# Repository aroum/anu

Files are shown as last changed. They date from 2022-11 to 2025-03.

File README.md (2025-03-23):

# Anu

[Anu](https://en.wikipedia.org/wiki/Anu) - compact stick mouse.

Gerber files and stl models can be downloaded in [releases](https://github.com/aroum/anu/releases).

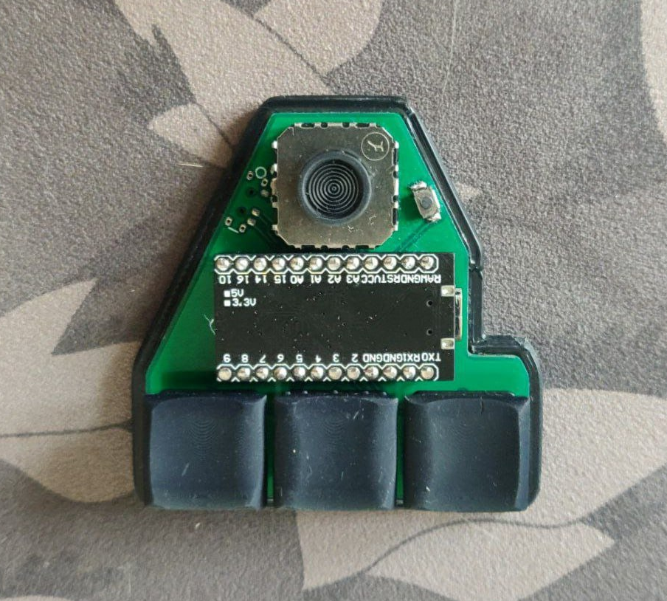
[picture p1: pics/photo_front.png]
front


# Features
* PSP analog stick 
* 3 keys, Kailh Choc V1 switches
* Choc spacing
* Direct pins 
* Wireless(optional)
* Per switch RGB(optional)
* Power switch for wireless controllers(optional)
* 100x100 mm panel pcb

# Firmware

Anu can be used with [nRFMicro](https://github.com/joric/nrfmicro) or [nice!nano](https://nicekeyboards.com/nice-nano/) and 301230 batteries for wireless mode. Currently ZMK does not support analog sticks.

The original idea was to create a compact "mouse" ([layout](http://www.keyboard-layout-editor.com/#/gists/458957846f6c65296a02e8bd9ae2c3ca)), but it can also be used as a gamepad. Gamepad firmare use [ArduinoGamepad library](https://github.com/gamelaster/ArduinoGamepad). For more detailed settings of the gamepad, you can use [TocaEdit XBOX 360 CE](https://www.x360ce.com/).

You can use the [threeboard layout](https://github.com/taylorconor/threeboard) to enter text using Anu.

Other configs using the analog stick [1](https://blog.ffff.lt/posts/joystick-algorithms/) & [2](https://github.com/CarrasTec/JoystickQMK/tree/main/macrokrs).

Work on ZMK support is also [in progress](https://github.com/aroum/zmk-anu/).

# BOM

| Item | Quantity | Remarks |
| --- | ---: | --- |
| [proMicro](https://aliexpress.ru/item/32840365436.html) | 1 | or any other compatible controller |
| [Kailh Choc V1](https://aliexpress.ru/item/32959996455.html) | 3  switches |
| [FJ08K-S](https://aliexpress.ru/item/1005006435837883.html) or [FJ08K](https://aliexpress.ru/item/32979957864.html) | 1 | analog stick. FJ08K-S has an additional button  |
| [Keycaps](https://aliexpress.ru/item/33026798318.html) | 3 | 1U |
| [YS-SK6812MINI-E](https://aliexpress.ru/item/4000475685852.html) | 3 | RGB leds |
| [Magnets](https://aliexpress.ru/item/1005002757445161.html) | 3-5 | disc 7x2 mm (for case) |
| [Bumpon](https://aliexpress.ru/item/4001188580018.html) | 8 | 5x2 mm |
| [Sockets PH3.5](https://aliexpress.ru/item/32899635835.html) | 12x2 | for controller |
| [SMD button 3x4x2mm](https://aliexpress.ru/item/1005003812819985.html) | 1 | for reset |
| [MSK-12C02](https://aliexpress.ru/item/1005001398386692.html) | 1 | Power switch  (wireless only) |
| [301230](https://aliexpress.ru/item/32732458079.html) | 1 | Battery  (wireless only) |
| [m2 nuts](https://aliexpress.ru/item/1005003114659036.html) | 4 | for case |
| [m2x4 screws](https://aliexpress.ru/item/1005004494509456.html) | 4 | for case |

[IBOM](https://htmlpreview.github.io/?https://github.com/aroum/anu/blob/master/pcb/ibom/ibom.html)

# Build guide
1. Solder the controller sockets
2. Solder the power switch (wireless only)
3. Solder the reset button
4. Solder the battery (only for wireless version)
5. Solder analog stick
6. Solder the pins into the controller
7. Solder 3 Kailh Choc V1 switches 
8. Solder 3 LEDs (RGB version only)
9. Put the keycaps on the switches and analog stick
10. Stick bumpon or place the keyboard in the case
11. Insert controller into sockets
12. Flash the bootloader (see the official manual for the controller)
13. Flash the firmware (see the official manual for the controller)

[Soldering Tutorial for Beginners](https://mightyohm.com/files/soldercomic/FullSolderComic_EN.pdf) ([RU version](https://sho0.neocities.org/downloads/komiks_payat_prosto.pdf))

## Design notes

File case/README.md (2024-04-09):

# CASE
 
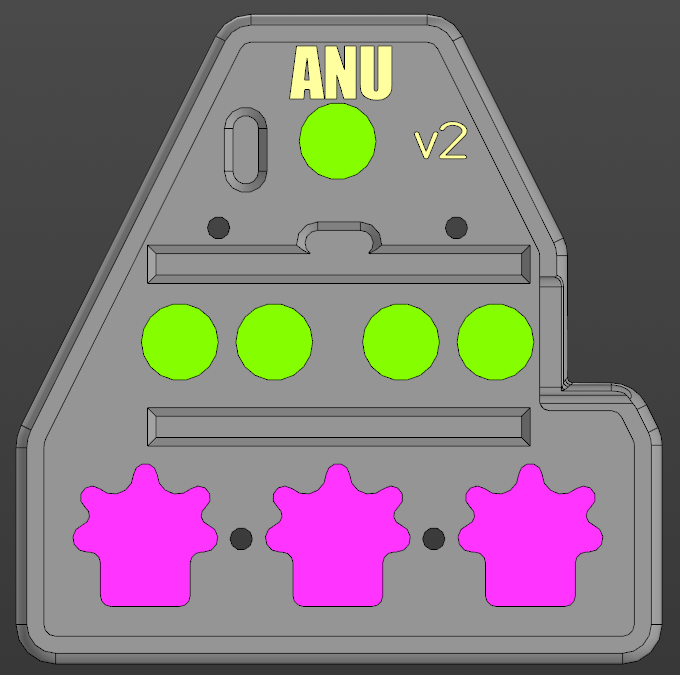
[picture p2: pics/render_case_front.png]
front

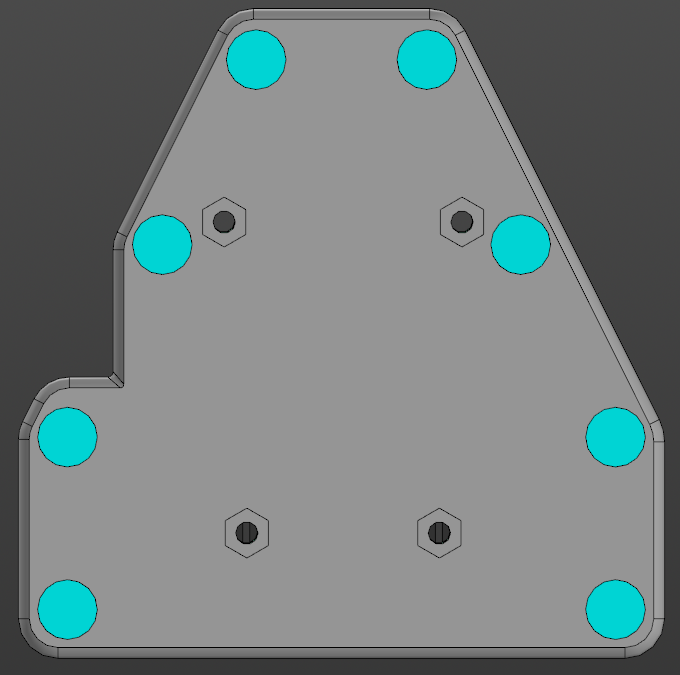
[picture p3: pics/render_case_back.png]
back


The pcb is fixed by friction or double-sided tape.

# BOM
* magnets size: 7x2mm (3-5 pcs)
* bumpons size: 5x2mm (8 pcs)
* nuts size: m2 (4 pcs)
* screws size: m2x4 (4 pcs)

# Print options:
* Printer: Voxelab proxima
* Rafts: No
* Supports: Yes
* Resolution: 0.05mm
* Resin material: ABS-like

The flexible version of the body does not have holes for non-slip feet.

STL and STEP models can be downloaded in [releases](https://github.com/aroum/anu/releases).

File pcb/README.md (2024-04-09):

# PCB
 
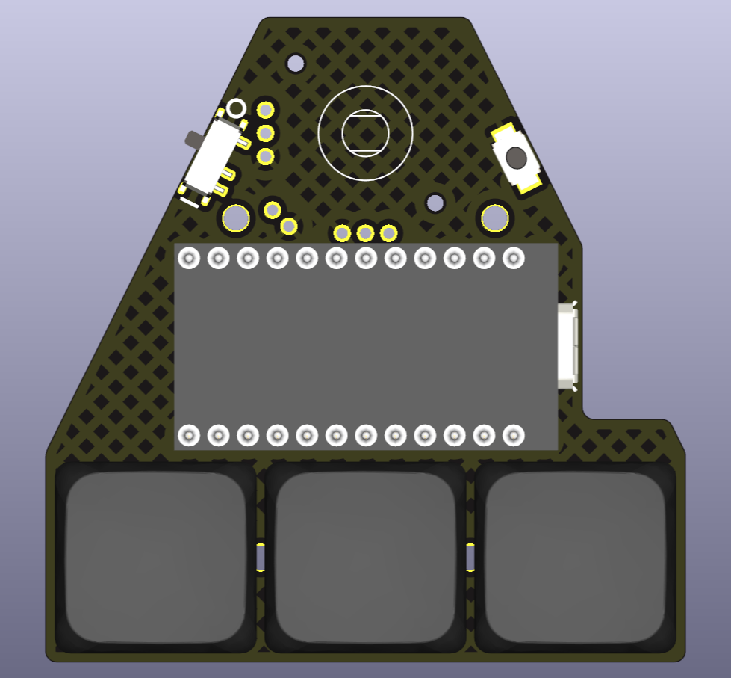
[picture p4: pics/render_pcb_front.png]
front

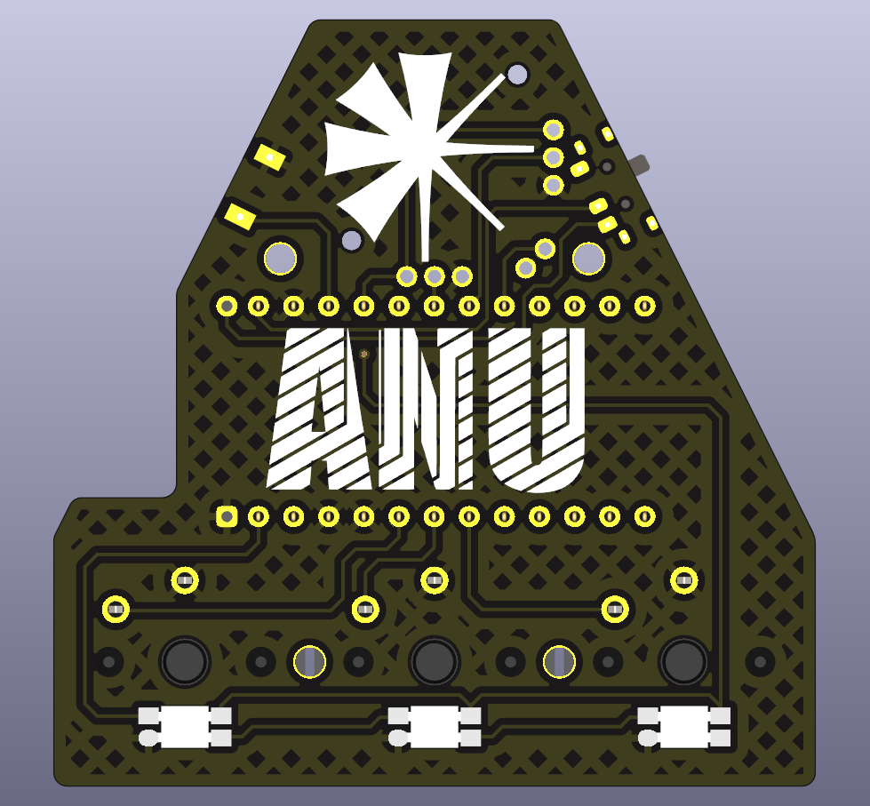
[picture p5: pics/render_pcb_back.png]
back


There is also the option of two PCBs fitted into 100x100 mm.

Gerber files can be downloaded in [releases](https://github.com/aroum/anu/releases).

[IBOM](https://htmlpreview.github.io/?https://github.com/aroum/anu/blob/master/pcb/ibom/ibom.html)

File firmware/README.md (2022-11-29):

# Firmware

## KLE

[Layout on the KLE website](http://www.keyboard-layout-editor.com/#/gists/458957846f6c65296a02e8bd9ae2c3ca)

## QMK
 
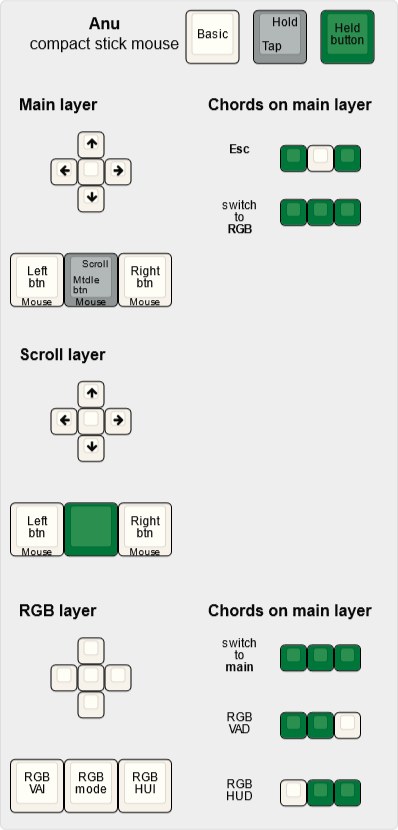
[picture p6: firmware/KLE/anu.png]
layout


* copy folder QMK/anu to qmk/keyboards
* run ```qmk compile -kb anu -km default```

Or just download in [releases](https://github.com/aroum/anu/releases).

## ZMK

Waiting for adding support mouse and analog read func.

## Arduino
* install [arduino gamepad lib](https://github.com/elanthis/gamepad)
* build
* install [x360ce](https://www.x360ce.com/) [optional]

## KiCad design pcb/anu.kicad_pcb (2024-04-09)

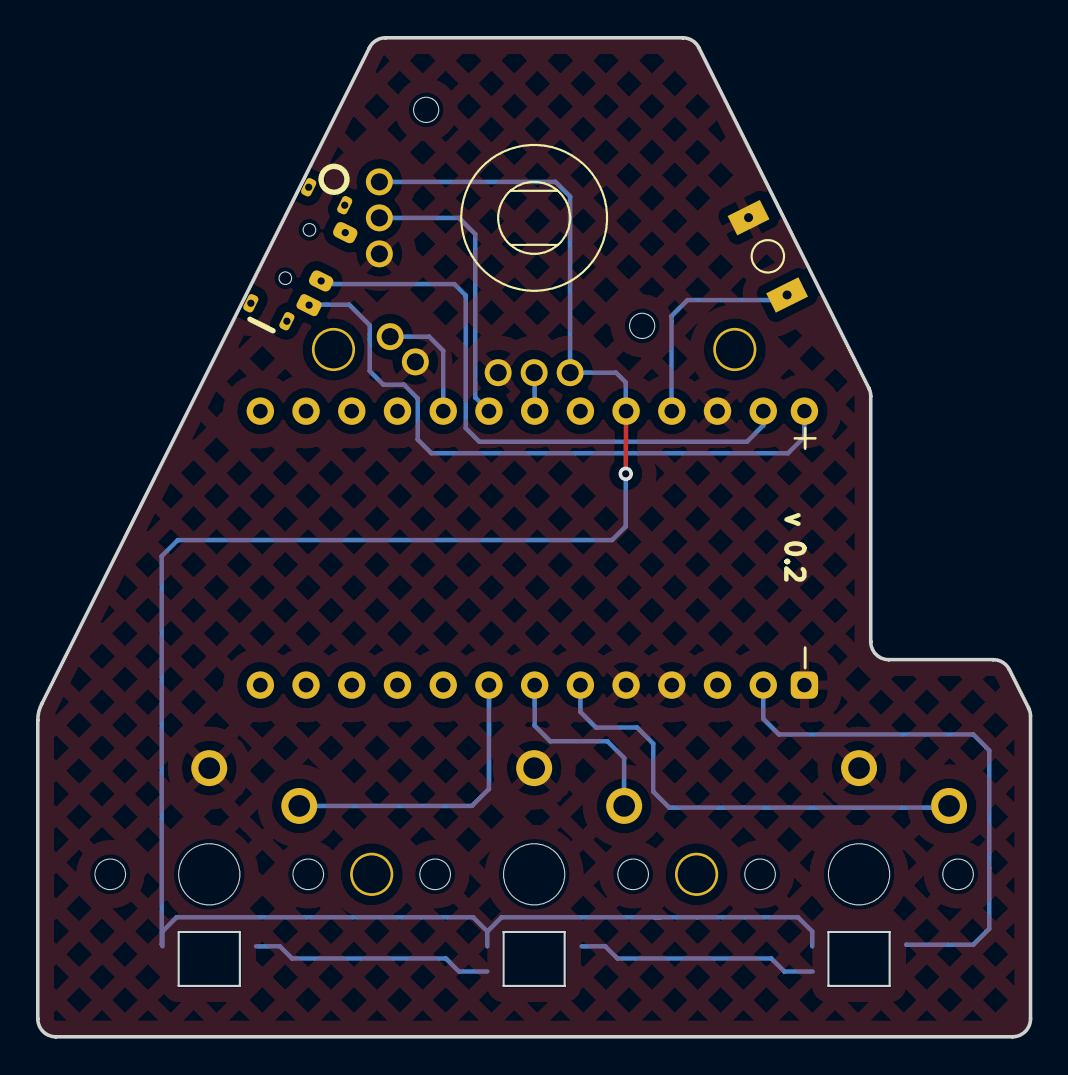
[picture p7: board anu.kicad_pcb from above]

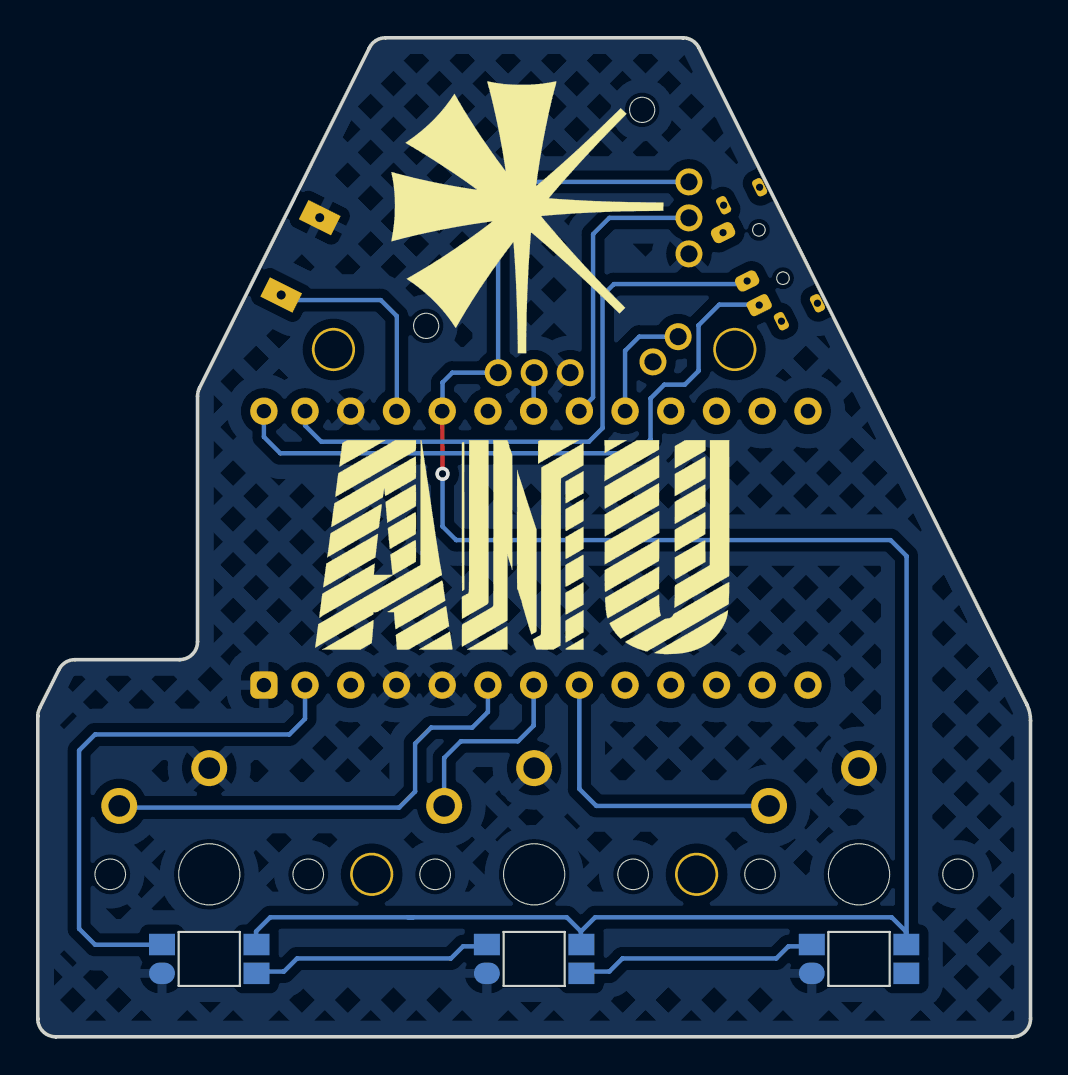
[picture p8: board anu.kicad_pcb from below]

Board: 2 copper layers, 55.2 x 55.5 mm, 17 parts (5 on the bottom side), 14 nets.

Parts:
G1: Logo; Logo_anu_cuneiform
G2: Logo; Logo_anu
H1, H1#2, H1#3, H1#4: Hole; HOLE
J1: battery connector; battery_conn_duplex
LED1, LED2, LED3: YS-SK6812MINI-E; YS-SK6812MINI-E_small
RSW1: SW_PUSH; SW_3x4x2_2legs
SW1, SW2, SW3: SW_PUSH; ChocV1_1u
SW4: SW_SPDT; SW_MSK-12C02_duplex
U1: ProMicro_r; ProMicro_v4
X1: FJ08K-S

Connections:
GND: J1.2, LED1.3 (GND), LED2.3 (GND), LED3.3 (GND), RSW1.2, SW1.2, SW2.2, SW3.2, U1.3 (GND), U1.4 (GND), U1.23 (GND), X1.A (SW1), X1.X3 (VCC), X1.Y1 (VCC)
LED: LED3.4 (DIN), U1.1 (D3/TX0)
unnamed: J1.1, SW4.3 (C)
unnamed: LED1.4 (DIN), LED2.2 (DOUT)
unnamed: LED2.4 (DIN), LED3.2 (DOUT)
VBAT: SW4.2 (B), U1.24 (RAW)
VCC: LED1.1 (VDD), LED2.1 (VDD), LED3.1 (VDD), U1.21 (VCC), X1.X1 (GND), X1.Y3 (GND)
analogX: U1.18 (A1/F6), X1.X2 (outX)
analogY: U1.19 (A2/F5), X1.Y2 (outY)
reset: RSW1.1, U1.22 (RST)
sw1: SW1.1, U1.7 (D4/4)
sw2: SW2.1, U1.6 (SCL/D0/3)
sw3: SW3.1, U1.5 (SDA/D1/2)
sw4: U1.17 (A0/F7), X1.B (SW2)

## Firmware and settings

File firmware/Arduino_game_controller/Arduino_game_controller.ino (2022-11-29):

#include <Gamepad.h>


int leftXcenter = 500;
int leftYcenter = 500;
double multiplierLX = 0.254;
double multiplierLY = 0.254;

Gamepad gp;

void setup() {
  pinMode(A1, INPUT);
  pinMode(A2, INPUT);
  pinMode(4,  INPUT_PULLUP); //A
  pinMode(3,  INPUT_PULLUP); //X
  pinMode(2,  INPUT_PULLUP); //B  
  
  calibrate();
}

void loop() {
  int lx, ly;
  lx = analogRead(A1);
  ly = analogRead(A2);
  //we need to convert a 0-1000 to -127 - 127
  lx = floor((lx - leftXcenter) * multiplierLX);
  ly = floor((ly - leftYcenter) * multiplierLY);
  if(lx > 127) lx = 127;
  if(ly > 127) ly = 127;
  gp.setLeftXaxis(lx);
  gp.setLeftYaxis(ly);
  
  int UPLEFT, UPRIGHT, UP, DOWN, LEFT, RIGHT, RIGHTBUTTON, LEFTBUTTON, X, Y, A, B;
  A = digitalRead(4);
  X = digitalRead(3);
  B = digitalRead(2);
  

  if(A == LOW)
    gp.setButtonState(10, true);
  else
    gp.setButtonState(10, false);  
  if(X == LOW)
    gp.setButtonState(8, true);
  else
    gp.setButtonState(8, false);
  if(B == LOW)
    gp.setButtonState(11, true);
  else
    gp.setButtonState(11, false);       

  delay(20);
}

void calibrate()
{
  int lx, ly;
  int i = 0;
  while(i < 13)
  {
    lx = analogRead(A3);
    ly = analogRead(A2);
    bool validLX = lx > (leftXcenter - 100) && lx < (leftXcenter + 100);
    bool validLY = ly > (leftYcenter - 100) && ly < (leftYcenter + 100);
    if(validLX && validLY)
      {
      i++;
      //nothing to do here!
    }
    else i = 0;
    delay(20);
  }
  leftXcenter = lx;
  leftYcenter = ly;
  multiplierLX = (double)127 / (double)lx;
  multiplierLY = (double)127 / (double)ly;
}

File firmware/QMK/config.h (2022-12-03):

#ifndef CONFIG_H
#define CONFIG_H

#include "config_common.h"


/* key matrix size */
#define MATRIX_ROWS 1
#define MATRIX_COLS 8

/* Set 0 if debouncing isn't needed */
#define DEBOUNCE 5

// /* prevent stuck modifiers */
// #define PREVENT_STUCK_MODIFIERS

#ifdef RGBLIGHT_ENABLE
#define RGB_DI_PIN D3
#define RGBLED_NUM 3 
#define DRIVER_LED_TOTAL RGBLED_NUM
#define RGBLIGHT_SLEEP
#define RGBLIGHT_LIMIT_VAL 180
#define RGBLIGHT_HUE_STEP 5
#define RGBLIGHT_SAT_STEP 10
#define RGBLIGHT_VAL_STEP 60
#define RGBLIGHT_EFFECT_STATIC_LIGHT
#define RGBLIGHT_EFFECT_TWINKLE
#define RGBLIGHT_LAYERS
#define RGBLIGHT_MAX_LAYERS 3
#define RGBLIGHT_LAYERS_OVERRIDE_RGB_OFF
#define RGBLIGHT_LAYERS
#endif

/* {BTN1, BTN2, BTN3, STICK_BTN}  */
#define DIRECT_PINS                        \
    {                                      \
        {                                  \
            D4, D0, D1, F7 \
        }                                  \
    }


/* Joystick */
// #define JOYSTICK_BUTTON_COUNT 4
#define JOYSTICK_AXES_COUNT 2
#define JOYSTICK_BUTTON_COUNT 1
#define JOYSTICK_AXIS_RESOLUTION 8


/* Joystick config */
#define ANALOG_JOYSTICK_X_AXIS_PIN F6
#define ANALOG_JOYSTICK_Y_AXIS_PIN F5
// #define ANALOG_JOYSTICK_CLICK_PIN F7

#define ANALOG_JOYSTICK_AXIS_MIN 0
#define ANALOG_JOYSTICK_AXIS_MAX 1023

#define ANALOG_JOYSTICK_READ_INTERVAL 10

#define POINTING_DEVICE_INVERT_X

#define JOYSTICK_AXIS_COUNT 2
#define JOYSTICK_BUTTON_COUNT 1
#define JOYSTICK_AXIS_RESOLUTION 8

/* Cursor speed */
#define ANALOG_JOYSTICK_SPEED_MAX 5
#define ANALOG_JOYSTICK_SPEED_REGULATOR 30

// #define TAP_CODE_DELAY 10
#define TAPPING_TERM 180
#define PERMISSIVE_HOLD

#define COMBO_COUNT 5
#endif

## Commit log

2024-04-09 add pcb & case
    [anu.kicad_pcb, anu.kicad_sch]
2024-04-09 add screws & panels
    [anu.kicad_pcb, anu_panel_100x100.kicad_pcb]
